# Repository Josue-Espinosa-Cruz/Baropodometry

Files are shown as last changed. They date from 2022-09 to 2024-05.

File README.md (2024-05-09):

# Baropodometry

1. **Printed Circuit Board:** 3D renders
    ~~~
    Electronic CAD: Autodesk EAGLE
    Computer-Aided Design Software: Fusion360

	1. Schematic Diagram
	2. CAD Model
	3. Renders
    ~~~
2. **Microcontroller:** Programming embedded system to acquire and visualize static plantar load distribution.
    ~~~
    Embedded System: MSP430-F5529 Launchpad
    Manufacturer:Texas Instruments 
    General specifications: 25 MHz MCU with 128KB Flash, 8KB SRAM
    ~~~

**Features applied:**
  1. GPIO pins
  2. Timer_A0
  3. 12-bit ADC
  4. UART protocol
  5. Interrupts

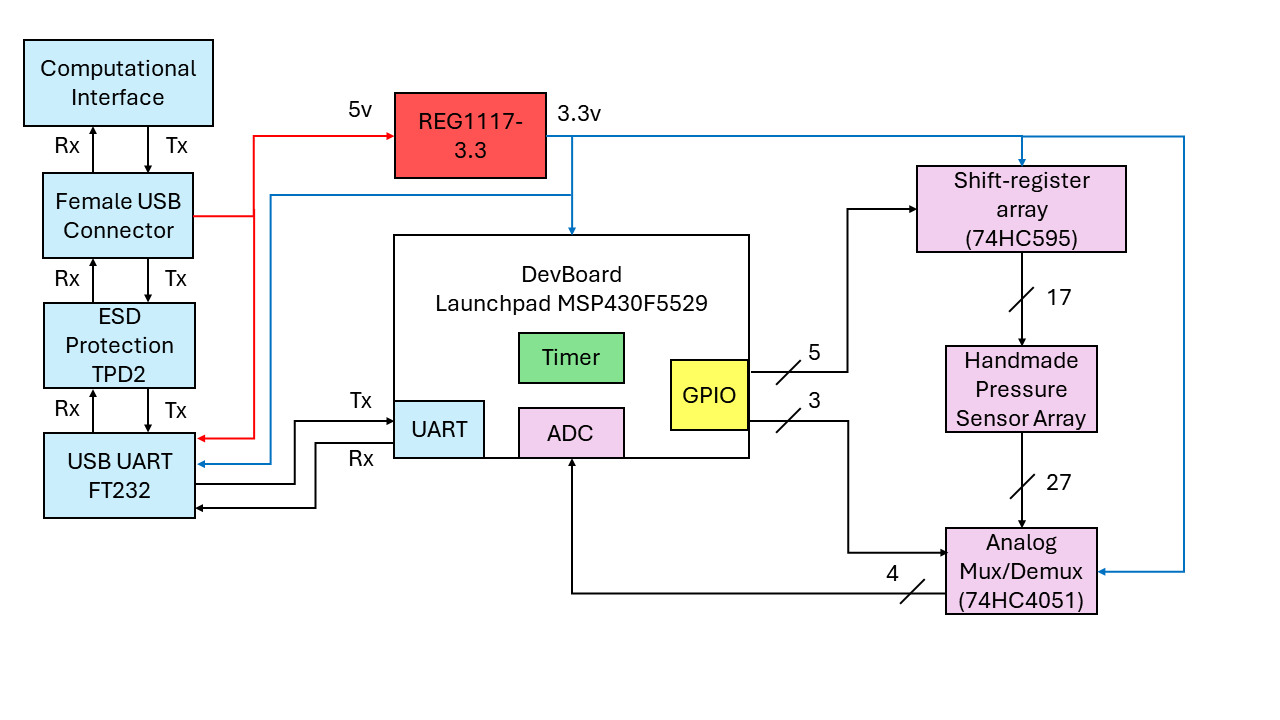
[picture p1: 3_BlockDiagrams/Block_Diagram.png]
BlockDiagram

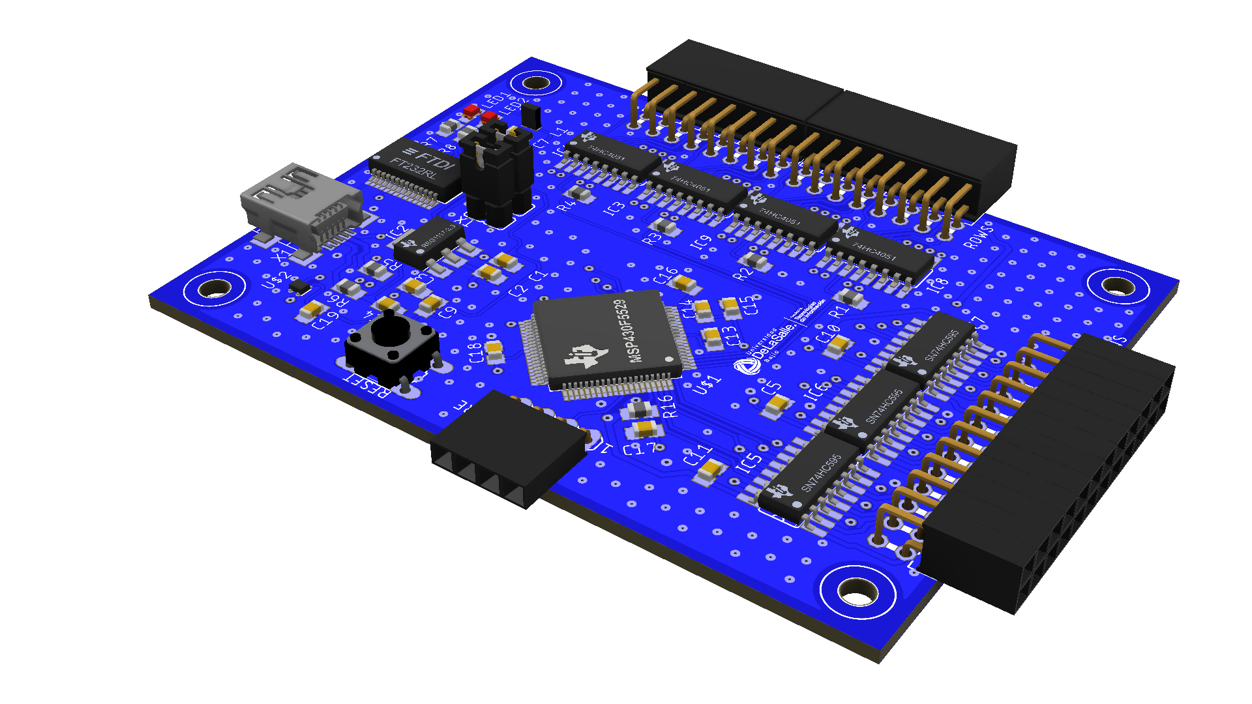
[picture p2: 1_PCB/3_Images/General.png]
PCB


## Credits
I would like to express special thanks to the following users on GrabCAD for their CAD models:

  1. Female Headers By DL2DW - Dirk Wouters
  2. Jumpler By DL2DW - Dirk Wouters
  3. Male Headers By - Vahagn Zargaryan
  4. Mini USB By [Unknown]

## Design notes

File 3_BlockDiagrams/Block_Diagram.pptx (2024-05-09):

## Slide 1

Computational Interface

5v

REG1117- 3.3

3.3v

Rx

Female USB Connector

Tx

Shift-register array
(74HC595)

DevBoard
Launchpad MSP430F5529

Rx

Tx

17

ESD Protection
TPD2

Timer

5

Handmade Pressure Sensor Array

Rx

Tx

Tx

UART

ADC

GPIO

3

USB UART
FT232

Rx

27

Analog Mux/Demux (74HC4051)

4

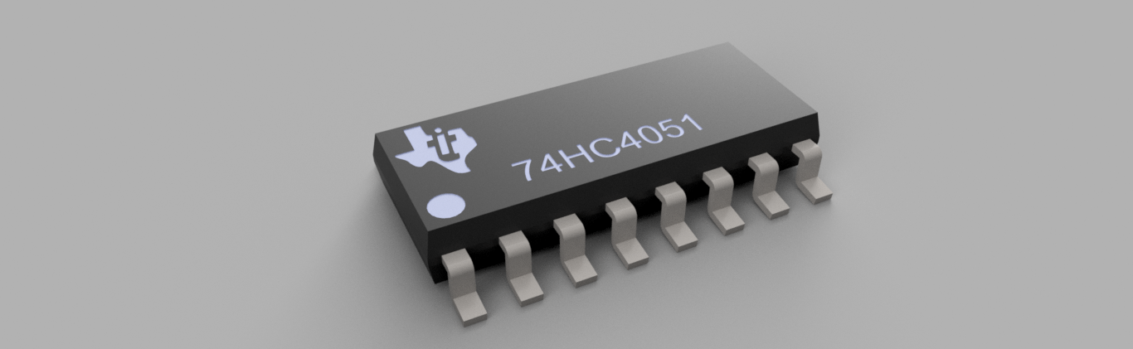
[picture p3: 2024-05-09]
1_PCB/2_CadModel/2_Components/2_OwnDesign/74HC4051-mux/74HC4051-mux_render.png

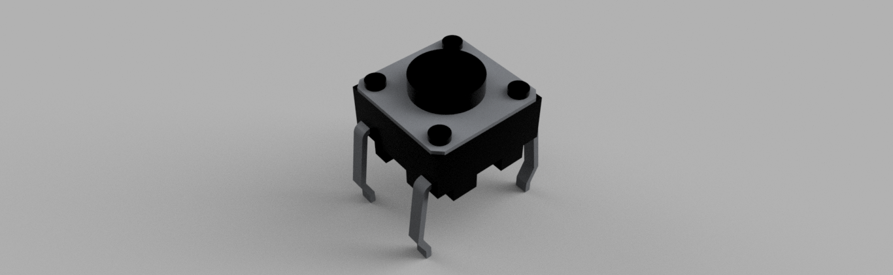
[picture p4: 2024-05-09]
1_PCB/2_CadModel/2_Components/2_OwnDesign/Pushbotton/Push.png

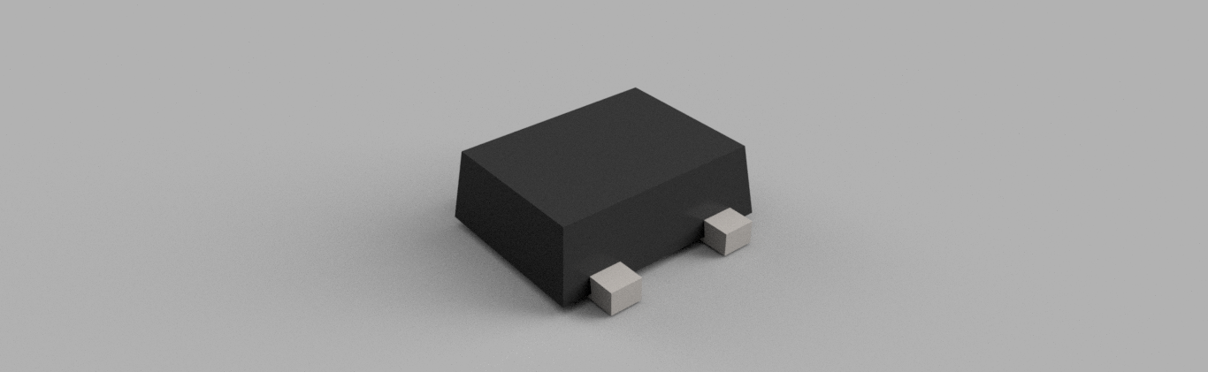
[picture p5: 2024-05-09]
1_PCB/2_CadModel/2_Components/2_OwnDesign/TP2/TPD2-render.png

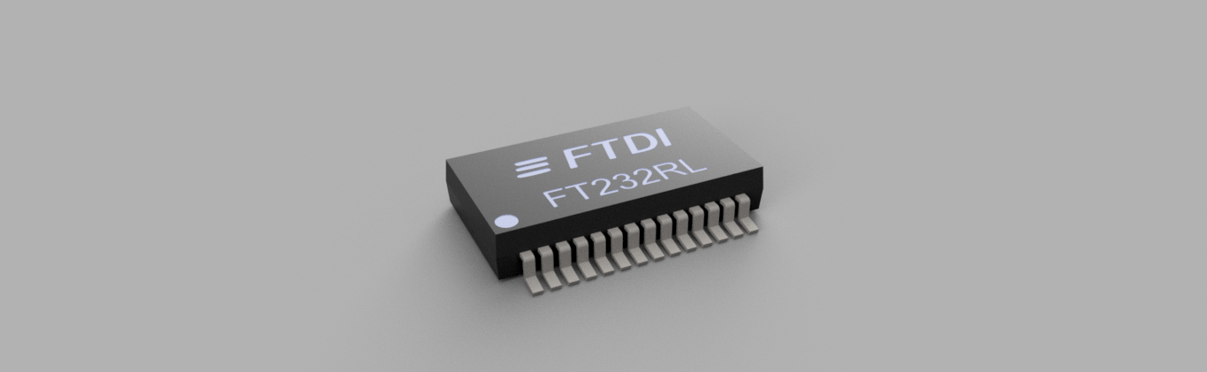
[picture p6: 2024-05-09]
1_PCB/2_CadModel/2_Components/2_OwnDesign/FT232/FT232-render.png

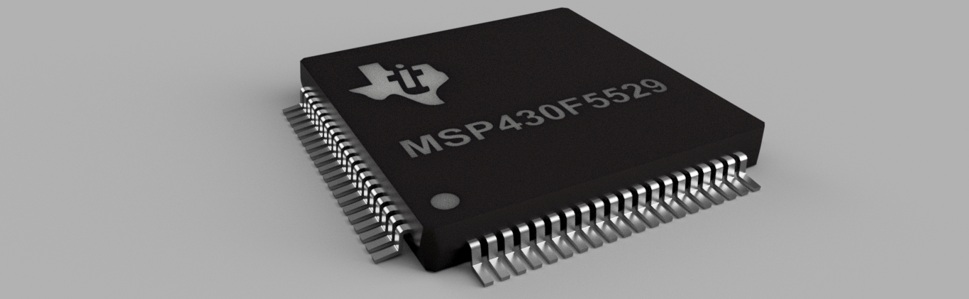
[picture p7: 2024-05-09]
1_PCB/2_CadModel/2_Components/2_OwnDesign/MSP430F5529/MSP430F5529-render.png

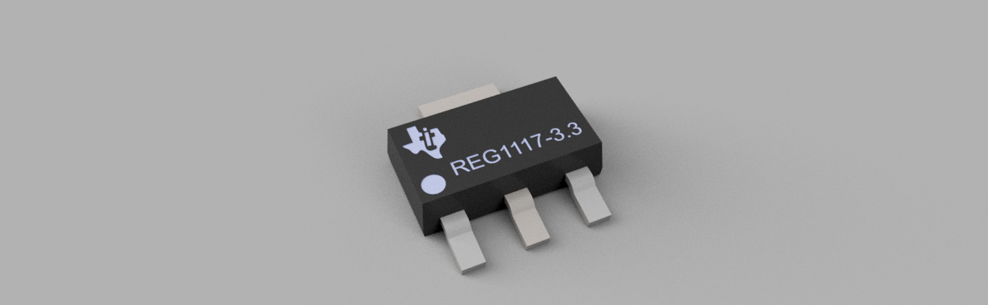
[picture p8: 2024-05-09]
1_PCB/2_CadModel/2_Components/2_OwnDesign/REG1117/REG1117-render.png

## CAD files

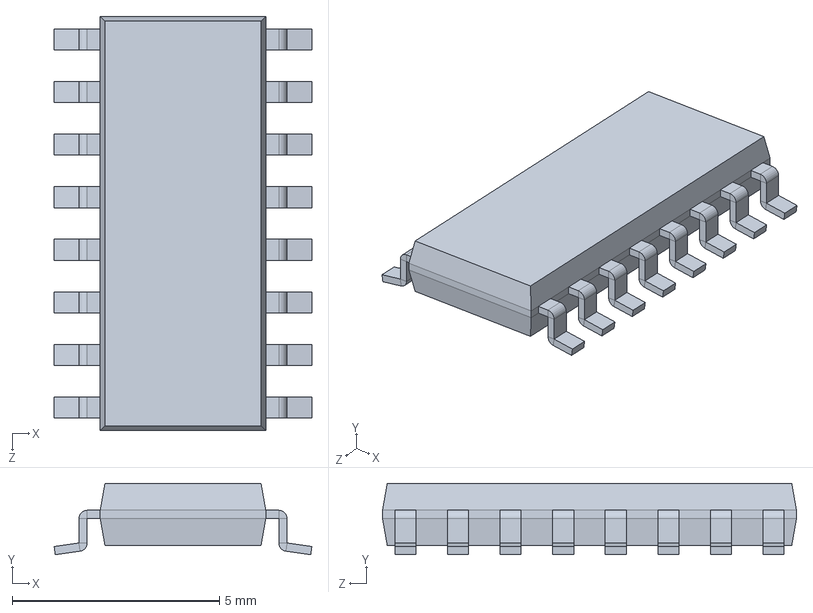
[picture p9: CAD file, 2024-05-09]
1_PCB/2_CadModel/2_Components/2_OwnDesign/74HC4051-mux/multiplexor.SLDPRT
6.23 x 1.72 x 10.0 mm

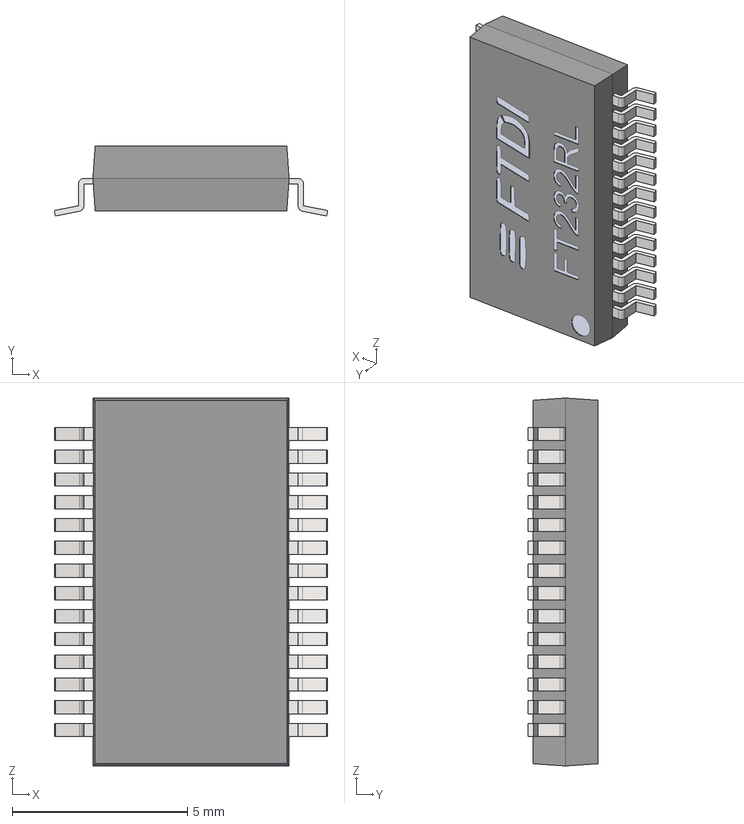
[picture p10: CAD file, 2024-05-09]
1_PCB/2_CadModel/2_Components/2_OwnDesign/FT232/FT232.STEP
7.80 x 2.00 x 10.5 mm

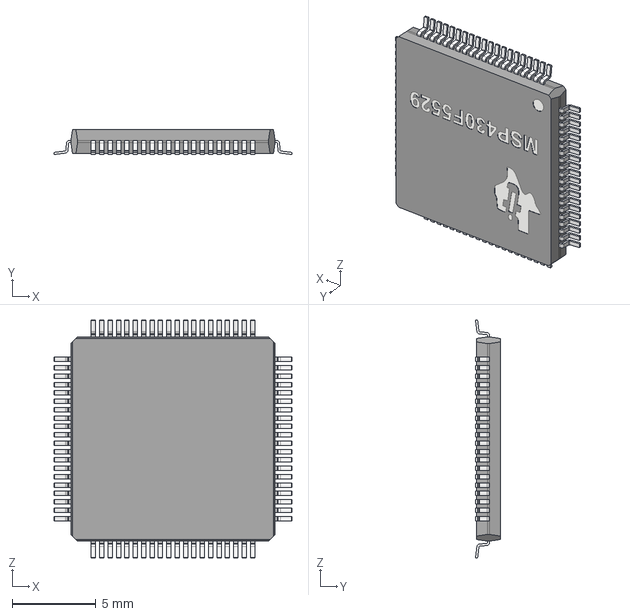
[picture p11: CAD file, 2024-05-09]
1_PCB/2_CadModel/2_Components/2_OwnDesign/MSP430F5529/MSP430F5529.step
14.2 x 1.50 x 14.2 mm

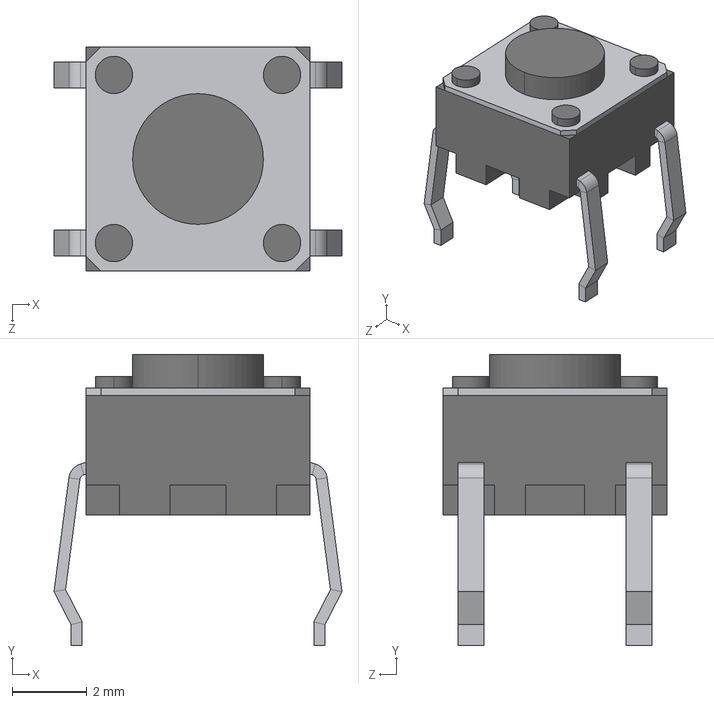
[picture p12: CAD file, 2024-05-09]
1_PCB/2_CadModel/2_Components/2_OwnDesign/Pushbotton/Push.STEP
7.71 x 7.80 x 6.00 mm

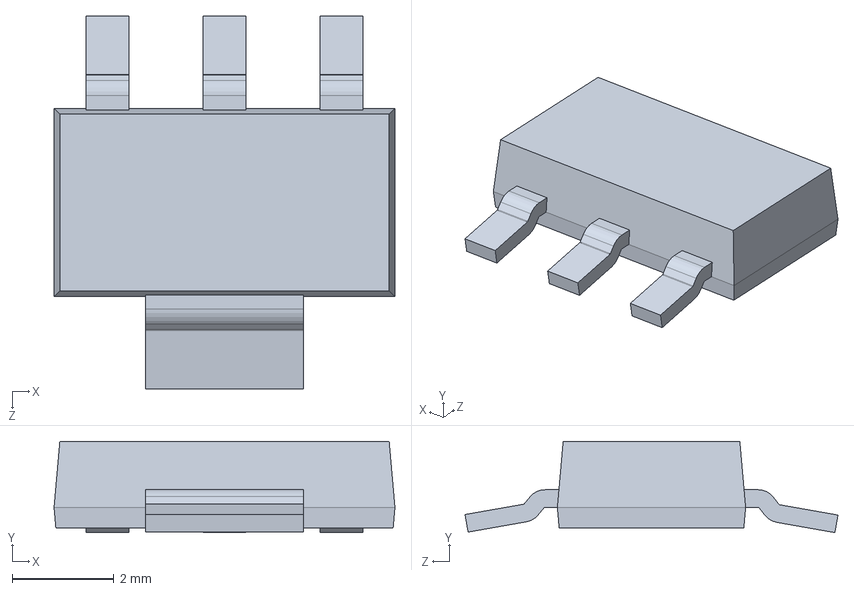
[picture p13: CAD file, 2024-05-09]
1_PCB/2_CadModel/2_Components/2_OwnDesign/REG1117/REG117.SLDPRT
6.70 x 1.79 x 7.33 mm

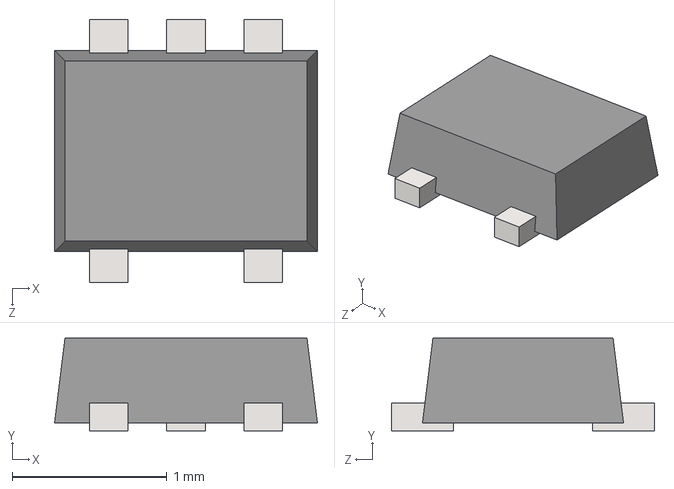
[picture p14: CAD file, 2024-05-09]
1_PCB/2_CadModel/2_Components/2_OwnDesign/TP2/TPD2.STEP
1.70 x 0.6 x 1.70 mm

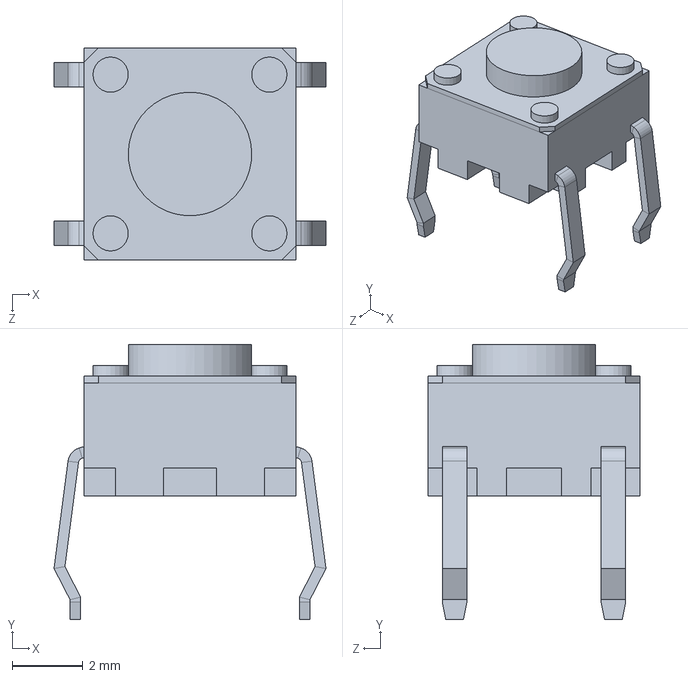
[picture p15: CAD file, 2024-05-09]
1_PCB/2_CadModel/2_Components/2_OwnDesign/Pushbotton/Push-render.SLDPRT
7.71 x 7.80 x 6.00 mm

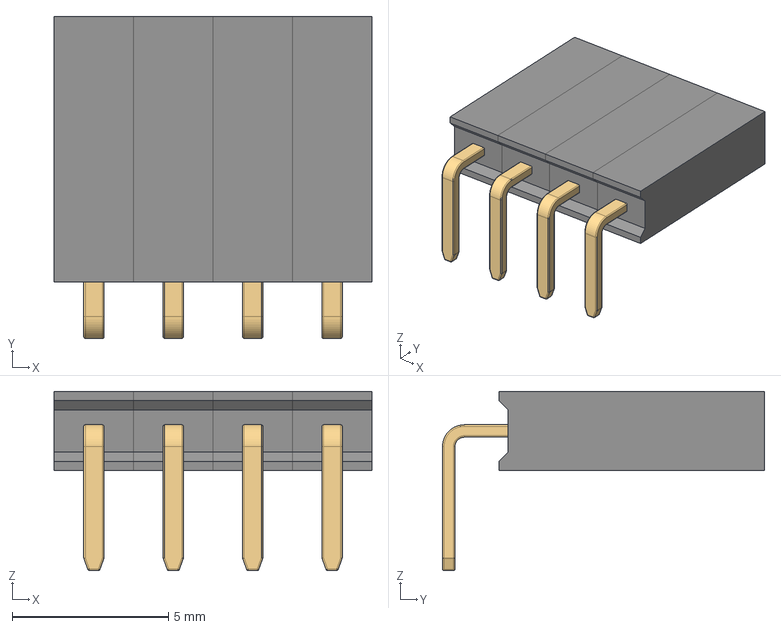
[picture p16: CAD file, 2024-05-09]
1_PCB/2_CadModel/2_Components/1_GrabCAD/Female Headers By DL2DW - Dirk Wouters/1 Row Female Pin Header Pitch 2.54mm Height 8.5mm Right Angle/Female Pin Header 01x04 Right Angle.stp
10.2 x 10.3 x 5.74 mm
Female Pin Header 1x Right Angle x 4

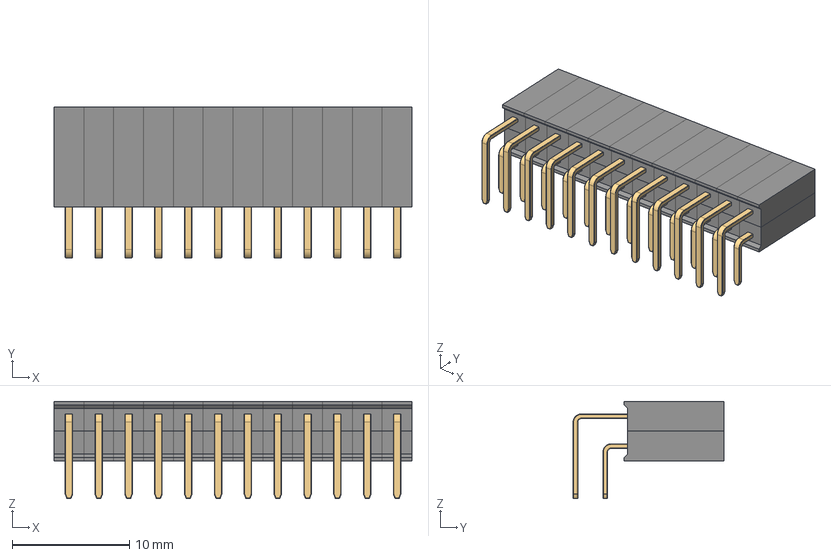
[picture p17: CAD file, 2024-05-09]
1_PCB/2_CadModel/2_Components/1_GrabCAD/Female Headers By DL2DW - Dirk Wouters/2 Row Female Pin Header Pitch 2.54mm Height 8.5mm Right Angle/Female Pin Header 02x12 Right Angle.stp
30.5 x 12.8 x 8.28 mm
Female Pin Header 1x Right Angle Upper x 12
Female Pin Header 1x Right Angle Bottom x 12

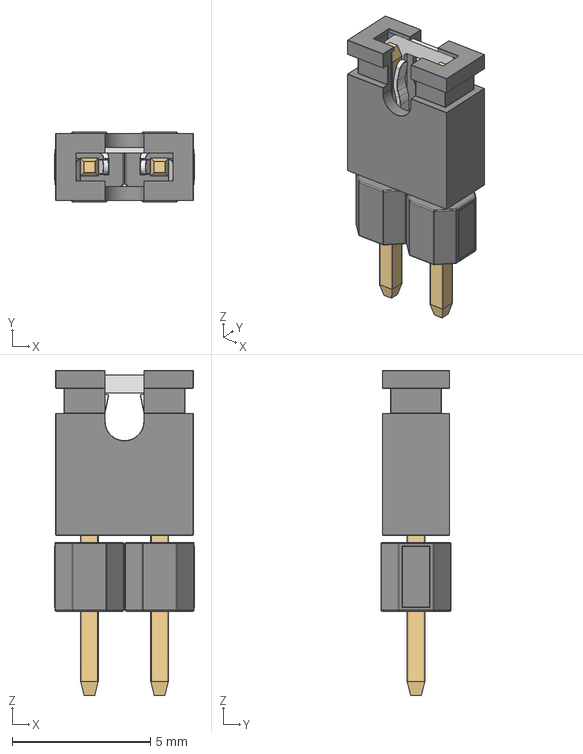
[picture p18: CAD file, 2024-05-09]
1_PCB/2_CadModel/2_Components/1_GrabCAD/Jumpler By DL2DW - Dirk Wouters/Jumper Closed.stp
5.08 x 2.54 x 11.8 mm

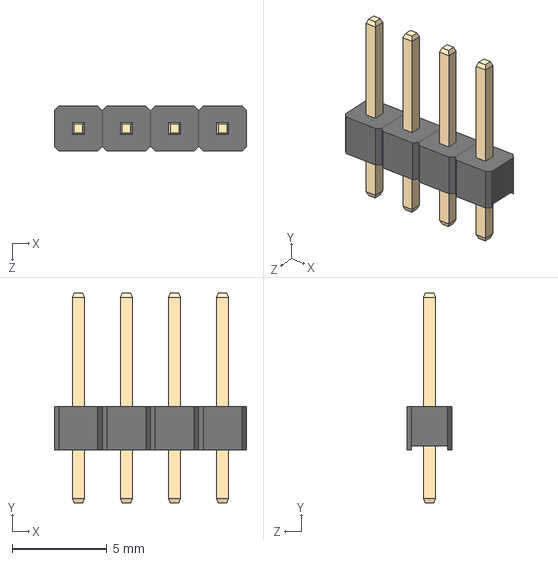
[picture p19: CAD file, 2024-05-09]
1_PCB/2_CadModel/2_Components/1_GrabCAD/Male Headers - Vahagn Zargaryan/4x_Male_Pin_2.54_mm.STEP
10.2 x 11.1 x 2.40 mm
1_Male_Pin_2.54_mm x 4

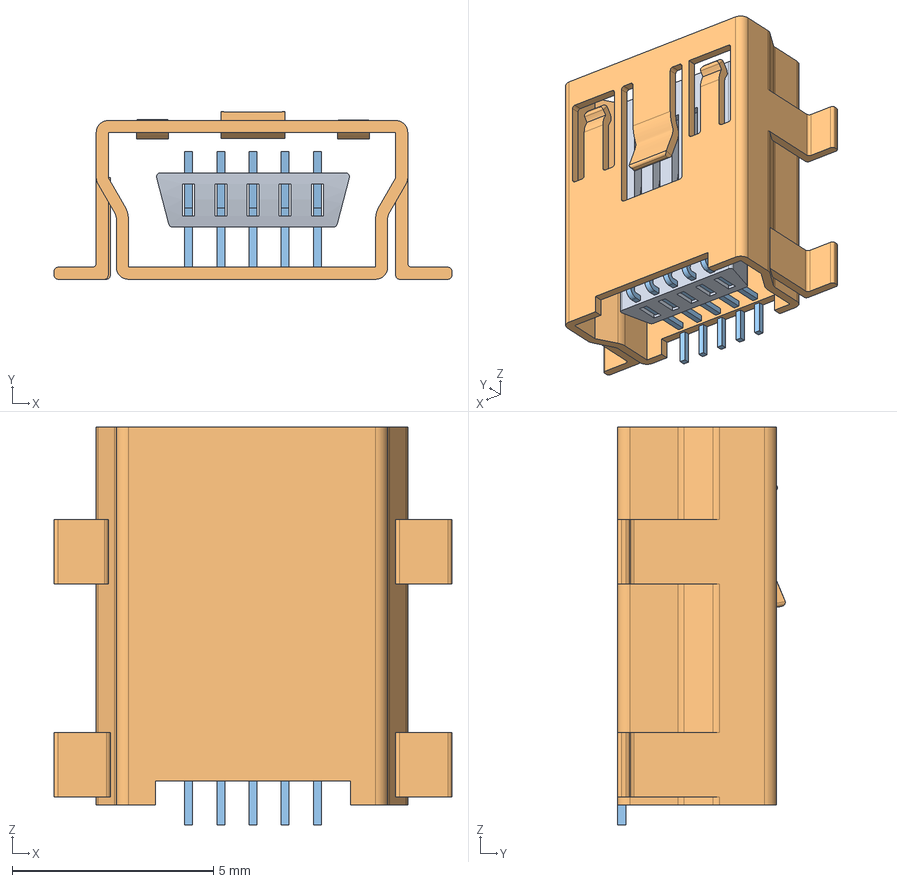
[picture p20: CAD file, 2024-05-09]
1_PCB/2_CadModel/2_Components/1_GrabCAD/Mini USB/USB_MINI_B_SMD v35.step
9.90 x 4.17 x 9.90 mm

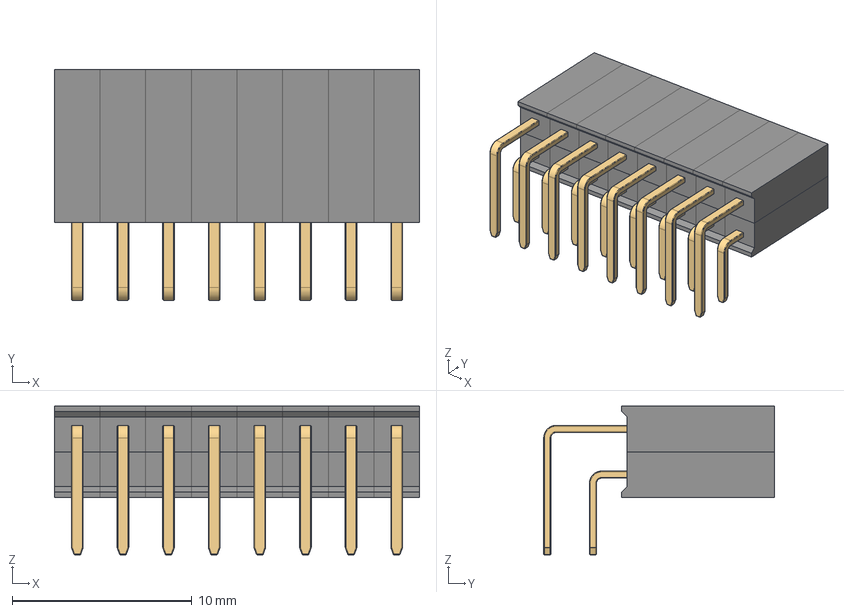
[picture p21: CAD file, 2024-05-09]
1_PCB/2_CadModel/2_Components/1_GrabCAD/Female Headers By DL2DW - Dirk Wouters/2 Row Female Pin Header Pitch 2.54mm Height 8.5mm Right Angle/Female Pin Header 02x08 Right Angle.stp
20.3 x 12.8 x 8.28 mm
Female Pin Header 1x Right Angle Upper x 8
Female Pin Header 1x Right Angle Bottom x 8

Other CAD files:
1_PCB/2_CadModel/2_Components/2_OwnDesign/74HC595-shift/74HC595-shift.step
1_PCB/2_CadModel/2_Components/2_OwnDesign/74HC4051-mux/74HC4051-mux.step
1_PCB/2_CadModel/2_Components/2_OwnDesign/REG1117/REG1117.step
1_PCB/2_CadModel/2_Components/1_GrabCAD/Mini USB/USB_MINI_B_SMD v35.f3d
1_PCB/2_CadModel/2_Components/2_OwnDesign/74HC4051-mux/74HC4051-mux.f3d
1_PCB/2_CadModel/2_Components/2_OwnDesign/74HC595-shift/74HC595-shift.f3d
1_PCB/2_CadModel/2_Components/2_OwnDesign/FT232/FT232.SLDPRT
1_PCB/2_CadModel/2_Components/2_OwnDesign/FT232/FT232.f3d
1_PCB/2_CadModel/2_Components/2_OwnDesign/MSP430F5529/MSP430F5529.f3d
1_PCB/2_CadModel/2_Components/2_OwnDesign/REG1117/REG1117.f3d
1_PCB/2_CadModel/2_Components/2_OwnDesign/TP2/TPD2.SLDPRT

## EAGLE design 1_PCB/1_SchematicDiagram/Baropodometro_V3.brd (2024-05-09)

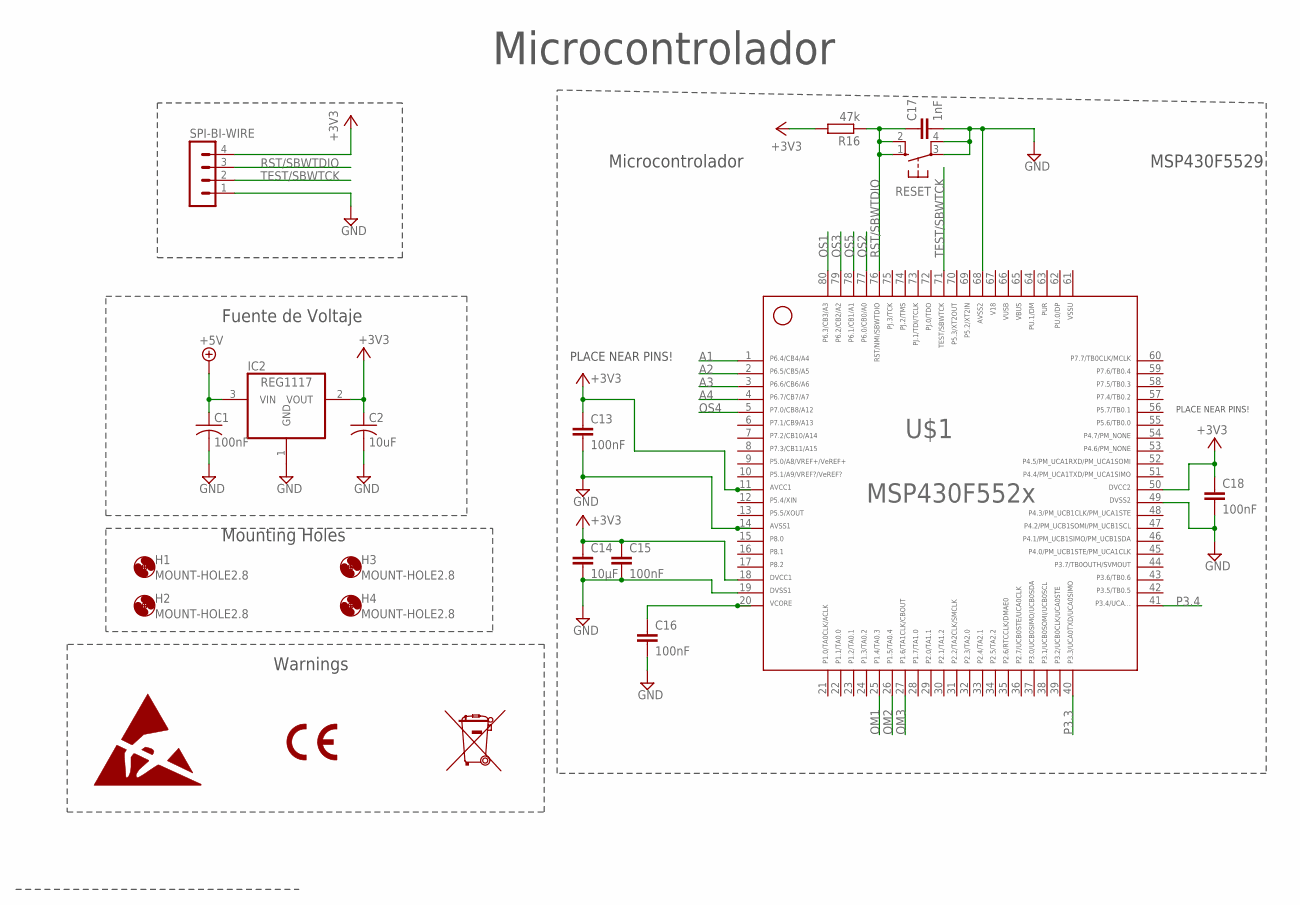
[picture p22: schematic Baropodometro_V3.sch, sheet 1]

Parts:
C1, C13, C15, C16, C18: 100nF; C0805
C2: 10uF; C0805
C14: 10µF; C0805
C17: 1nF; C0805
H1, H2, H3, H4: MOUNT-HOLE2.8; 2,8
IC2: REG1117; SOT223
R16: 47k; R0805
RESET: 10-XX; B3F-10XX
SPI-BI-WIRE: MA04-1
U$1: MSP430F5529; TI_MSP430_V16_INTERN_PN80

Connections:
61: U$1.61
65: U$1.65
66: U$1.66
67: U$1.67
+3V3: C2.1, C13.1, C14.1, C15.1, C18.1, IC2.2 (VOUT), R16.2, SPI-BI-WIRE.4, U$1.11, U$1.18, U$1.50; also elsewhere on the board
+5V: C1.1, IC2.3 (VIN); also elsewhere on the board
A1: U$1.1; also elsewhere on the board
A2: U$1.2; also elsewhere on the board
A3: U$1.3; also elsewhere on the board
A4: U$1.4; also elsewhere on the board
GND: C1.2, C2.2, C13.2, C14.2, C15.2, C16.2, C17.2, C18.2, IC2.1 (GND), RESET.3, RESET.4 (P1), SPI-BI-WIRE.1, U$1.14, U$1.19, U$1.49, U$1.68; also elsewhere on the board
unnamed: C16.1, U$1.20
OM1: U$1.25; also elsewhere on the board
OM2: U$1.26; also elsewhere on the board
OM3: U$1.27; also elsewhere on the board
OS1: U$1.80; also elsewhere on the board
OS2: U$1.77; also elsewhere on the board
OS3: U$1.79; also elsewhere on the board
OS4: U$1.5; also elsewhere on the board
OS5: U$1.78; also elsewhere on the board
P3.3: U$1.40; also elsewhere on the board
P3.4: U$1.41; also elsewhere on the board
RST/SBWTDIO: C17.1, R16.1, RESET.1 (S), RESET.2 (S1), SPI-BI-WIRE.3, U$1.76
TEST/SBWTCK: SPI-BI-WIRE.2, U$1.71

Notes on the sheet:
Fuente de Voltaje
Microcontrolador
MSP430F5529
Warnings
Mounting Holes
PLACE NEAR PINS!

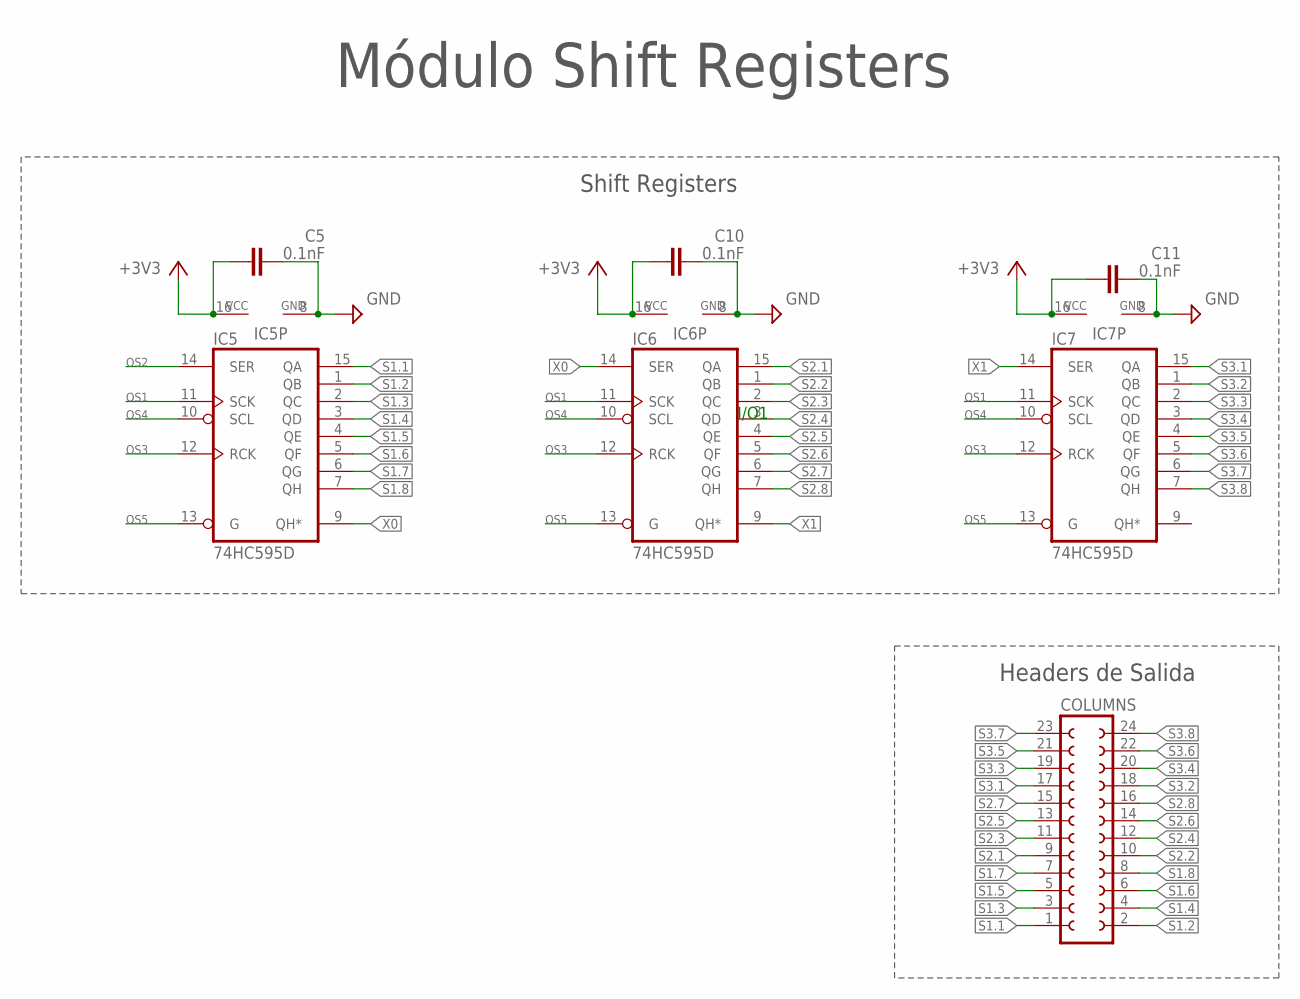
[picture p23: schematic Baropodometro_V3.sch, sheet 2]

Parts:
C5, C10, C11: 0.1nF; C0805
COLUMNS: FE12-2W
IC5, IC6, IC7: 74HC595D; SO16

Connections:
+3V3: C5.1, C10.1, C11.1, IC5.16 (VCC), IC6.16 (VCC), IC7.16 (VCC); also elsewhere on the board
GND: C5.2, C10.2, C11.2, IC5.8 (GND), IC6.8 (GND), IC7.8 (GND); also elsewhere on the board
OS1: IC5.11 (SCK), IC6.11 (SCK), IC7.11 (SCK); also elsewhere on the board
OS2: IC5.14 (SER); also elsewhere on the board
OS3: IC5.12 (RCK), IC6.12 (RCK), IC7.12 (RCK); also elsewhere on the board
OS4: IC5.10 (SCL), IC6.10 (SCL), IC7.10 (SCL); also elsewhere on the board
OS5: IC5.13 (G), IC6.13 (G), IC7.13 (G); also elsewhere on the board
S1.1: COLUMNS.1, IC5.15 (QA)
S1.2: COLUMNS.2, IC5.1 (QB)
S1.3: COLUMNS.3, IC5.2 (QC)
S1.4: COLUMNS.4, IC5.3 (QD)
S1.5: COLUMNS.5, IC5.4 (QE)
S1.6: COLUMNS.6, IC5.5 (QF)
S1.7: COLUMNS.7, IC5.6 (QG)
S1.8: COLUMNS.8, IC5.7 (QH)
S2.1: COLUMNS.9, IC6.15 (QA)
S2.2: COLUMNS.10, IC6.1 (QB)
S2.3: COLUMNS.11, IC6.2 (QC)
S2.4: COLUMNS.12, IC6.3 (QD)
S2.5: COLUMNS.13, IC6.4 (QE)
S2.6: COLUMNS.14, IC6.5 (QF)
S2.7: COLUMNS.15, IC6.6 (QG)
S2.8: COLUMNS.16, IC6.7 (QH)
S3.1: COLUMNS.17, IC7.15 (QA)
S3.2: COLUMNS.18, IC7.1 (QB)
S3.3: COLUMNS.19, IC7.2 (QC)
S3.4: COLUMNS.20, IC7.3 (QD)
S3.5: COLUMNS.21, IC7.4 (QE)
S3.6: COLUMNS.22, IC7.5 (QF)
S3.7: COLUMNS.23, IC7.6 (QG)
S3.8: COLUMNS.24, IC7.7 (QH)
X0: IC5.9 (QH*), IC6.14 (SER)
X1: IC6.9 (QH*), IC7.14 (SER)

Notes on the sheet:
I/O1
Shift Registers
Módulo Shift Registers
Headers de Salida

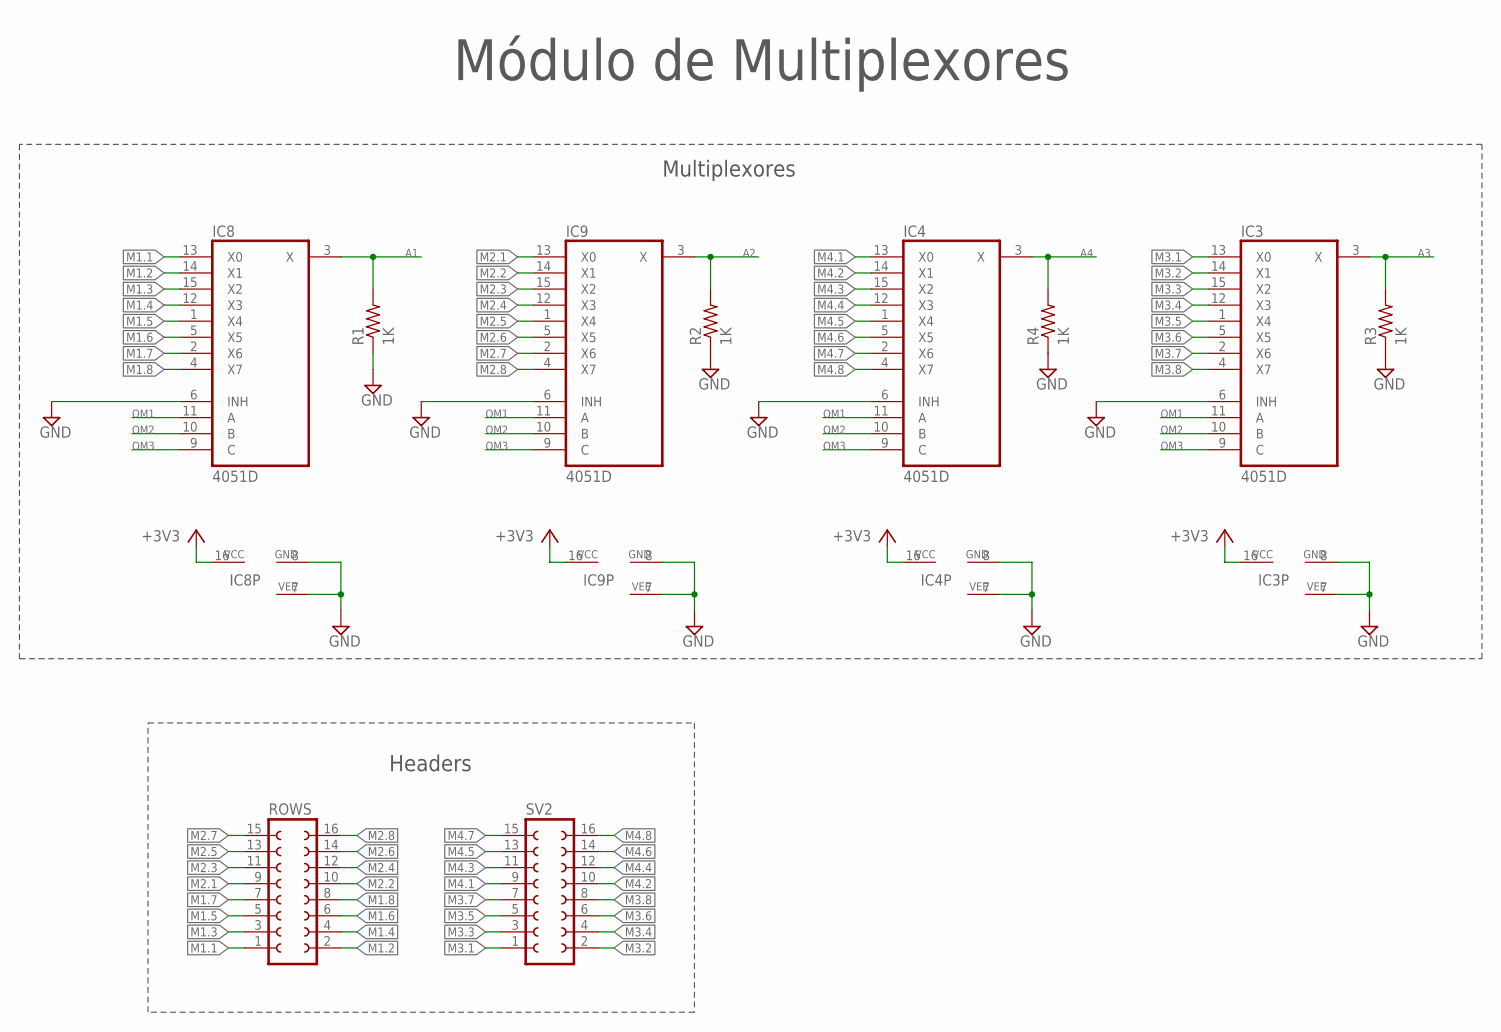
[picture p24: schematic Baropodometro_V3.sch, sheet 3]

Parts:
IC3, IC4, IC8, IC9: 4051D; SO16
R1, R2, R3, R4: 1K; R0805
ROWS: FE08-2W
SV2: FE08-2W

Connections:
+3V3: IC3.16 (VCC), IC4.16 (VCC), IC8.16 (VCC), IC9.16 (VCC); also elsewhere on the board
A1: IC8.3 (X), R1.2; also elsewhere on the board
A2: IC9.3 (X), R2.2; also elsewhere on the board
A3: IC3.3 (X), R3.2; also elsewhere on the board
A4: IC4.3 (X), R4.2; also elsewhere on the board
GND: IC3.6 (INH), IC3.7 (VEE), IC3.8 (GND), IC4.6 (INH), IC4.7 (VEE), IC4.8 (GND), IC8.6 (INH), IC8.7 (VEE), IC8.8 (GND), IC9.6 (INH), IC9.7 (VEE), IC9.8 (GND), R1.1, R2.1, R3.1, R4.1; also elsewhere on the board
M1.1: IC8.13 (X0), ROWS.1
M1.2: IC8.14 (X1), ROWS.2
M1.3: IC8.15 (X2), ROWS.3
M1.4: IC8.12 (X3), ROWS.4
M1.5: IC8.1 (X4), ROWS.5
M1.6: IC8.5 (X5), ROWS.6
M1.7: IC8.2 (X6), ROWS.7
M1.8: IC8.4 (X7), ROWS.8
M2.1: IC9.13 (X0), ROWS.9
M2.2: IC9.14 (X1), ROWS.10
M2.3: IC9.15 (X2), ROWS.11
M2.4: IC9.12 (X3), ROWS.12
M2.5: IC9.1 (X4), ROWS.13
M2.6: IC9.5 (X5), ROWS.14
M2.7: IC9.2 (X6), ROWS.15
M2.8: IC9.4 (X7), ROWS.16
M3.1: IC3.13 (X0), SV2.1
M3.2: IC3.14 (X1), SV2.2
M3.3: IC3.15 (X2), SV2.3
M3.4: IC3.12 (X3), SV2.4
M3.5: IC3.1 (X4), SV2.5
M3.6: IC3.5 (X5), SV2.6
M3.7: IC3.2 (X6), SV2.7
M3.8: IC3.4 (X7), SV2.8
M4.1: IC4.13 (X0), SV2.9
M4.2: IC4.14 (X1), SV2.10
M4.3: IC4.15 (X2), SV2.11
M4.4: IC4.12 (X3), SV2.12
M4.5: IC4.1 (X4), SV2.13
M4.6: IC4.5 (X5), SV2.14
M4.7: IC4.2 (X6), SV2.15
M4.8: IC4.4 (X7), SV2.16
OM1: IC3.11 (A), IC4.11 (A), IC8.11 (A), IC9.11 (A); also elsewhere on the board
OM2: IC3.10 (B), IC4.10 (B), IC8.10 (B), IC9.10 (B); also elsewhere on the board
OM3: IC3.9 (C), IC4.9 (C), IC8.9 (C), IC9.9 (C); also elsewhere on the board

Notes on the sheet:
Headers
Multiplexores
Módulo de Multiplexores

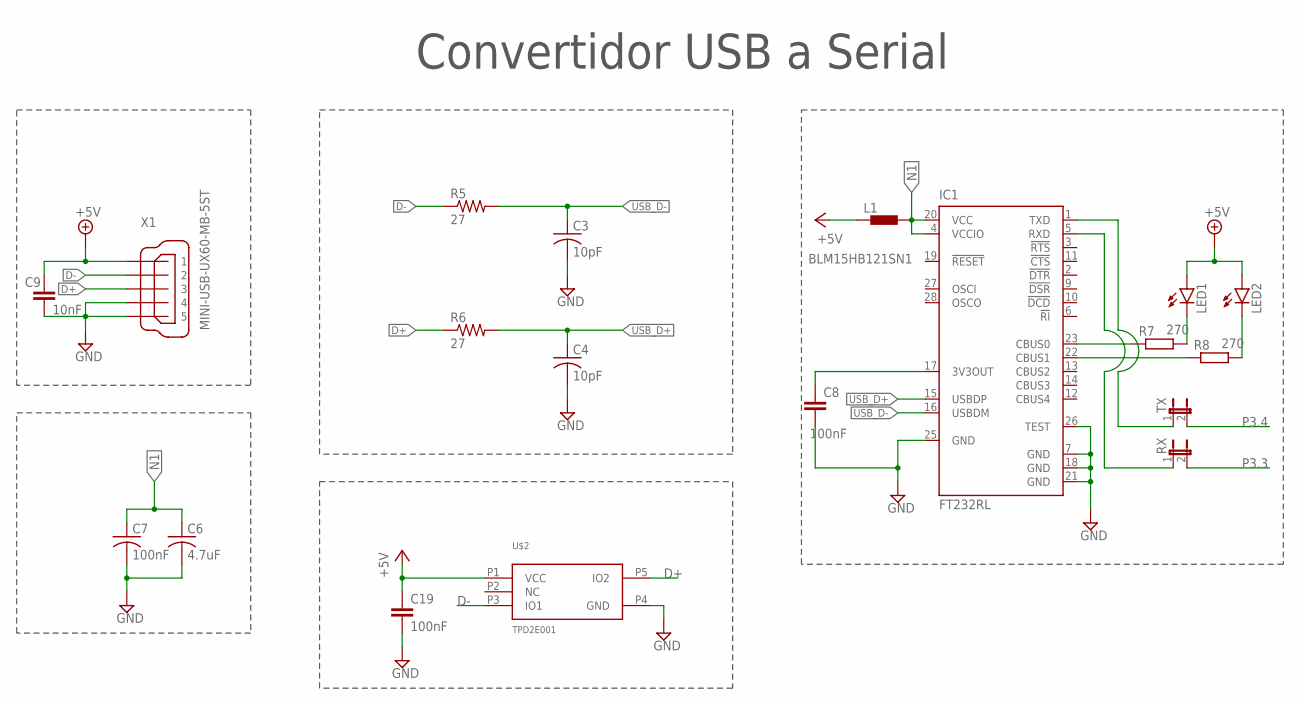
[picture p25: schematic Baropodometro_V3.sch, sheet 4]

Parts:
C3, C4: 10pF; C0805
C6: 4.7uF; C0805
C7, C8, C19: 100nF; C0805
C9: 10nF; C0805
IC1: FT232RL; SSOP28
L1: BLM15HB121SN1; 0402
LED1, LED2: LEDCHIP-LED0805; CHIP-LED0805
R5, R6: 27; R0805
R7, R8: 270; R0805
RX: JP1E; JP1
TX: JP1E; JP1
U$2: TPD2E001; SOT-5
X1: MINI-USB-UX60-MB-5ST; UX60-MB-5ST

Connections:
+5V: C9.1, C19.1, L1.1, LED1.A, LED2.A, U$2.P1 (VCC), X1.1; also elsewhere on the board
D+: R6.1, U$2.P5 (IO2), X1.3
D-: R5.1, U$2.P3 (IO1), X1.2
GND: C3.2, C4.2, C6.2, C7.2, C8.2, C9.2, C19.2, IC1.7 (GND), IC1.18 (GND), IC1.21 (GND), IC1.25 (GND), IC1.26 (TEST), U$2.P4 (GND), X1.4, X1.5; also elsewhere on the board
N1: C6.1, C7.1, IC1.4 (VCCIO), IC1.20 (VCC), L1.2
unnamed: LED1.C, R7.2
unnamed: IC1.22 (CBUS1), R8.1
unnamed: IC1.23 (CBUS0), R7.1
unnamed: LED2.C, R8.2
unnamed: IC1.1 (TXD), TX.1
unnamed: IC1.5 (RXD), RX.1
unnamed: C8.1, IC1.17 (3V3OUT)
P3.3: RX.2; also elsewhere on the board
P3.4: TX.2; also elsewhere on the board
USB_D+: C4.1, IC1.15 (USBDP), R6.2
USB_D-: C3.1, IC1.16 (USBDM), R5.2

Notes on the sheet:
Convertidor USB a Serial

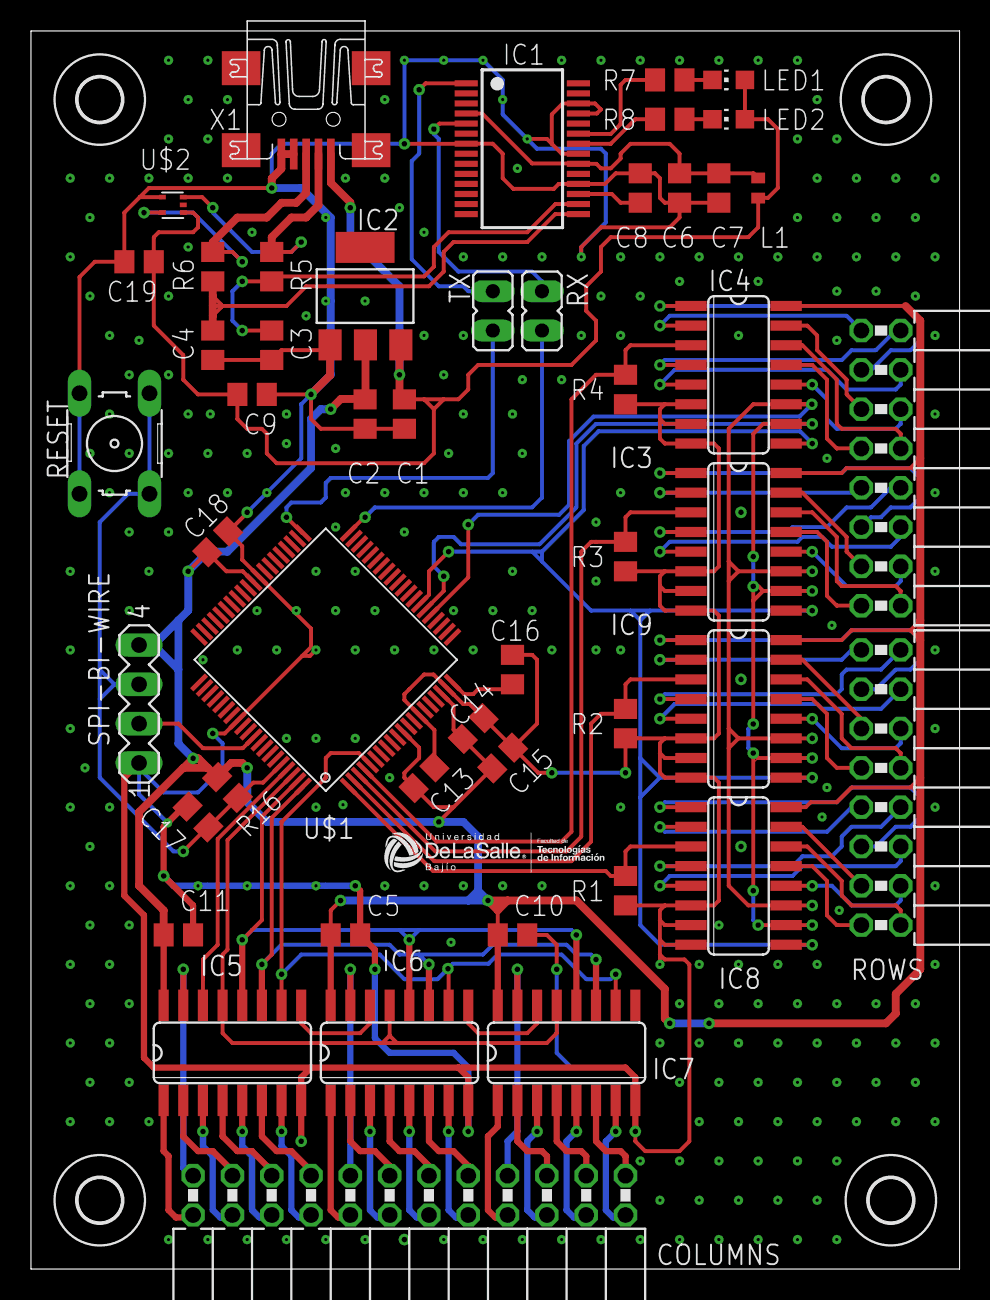
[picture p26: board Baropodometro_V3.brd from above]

Board: 2 copper layers, 60.0 x 80.0 mm, 53 parts (0 on the bottom side), 90 nets.

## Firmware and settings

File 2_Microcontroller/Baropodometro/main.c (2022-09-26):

#include <msp430.h>

/**
 * main.c
 *  Autor: C. Josué Espinosa Cruz
 *  Fecha: 10 de mayo de 2020
 *
 *
 *  El voltaje se varía con un potenciómetro externo.
 */

unsigned int valor_adc_binario1 = 0;
unsigned int valor_adc_binario2 = 0;
unsigned int valor_adc_binario3 = 0;
unsigned int valor_adc_binario4 = 0;

unsigned int tx_buffer[459]; //unsigned char

unsigned char i = 0;

unsigned char bandera_inicializar = 0x00;
unsigned int contador_general = 0;
unsigned int contador_timer = 0;
unsigned int contador_timer2 = 0;
unsigned int contador_timer3 = 0;

unsigned int contador_arreglo1 = 0;
unsigned int contador_arreglo2 = 8;
unsigned int contador_arreglo3 = 16;
unsigned int contador_arreglo4 = 24;

unsigned int contador_arreglo1_2 = 0;
unsigned int contador_arreglo2_2 = 0;
unsigned int contador_arreglo3_2 = 0;
unsigned int contador_arreglo4_2 = 0;

unsigned char banderaADC_Activar = 0x00;
unsigned char banderaTimer_Activar = 0x00;

void Configurar_GPIO(void)
{
    //Señal_Funcionamiento_TimerA0
    P1DIR |= 0x01;                                   // Se configura el bit 0 del puerto 1 como salida. Los demás bits, como entrada.
    P1OUT = 0x00;                                   // Se ponen todos los pines del puerto 1 en 0 (en LOW).

    //Output Contador_Multiplexor_Columnas
    P4DIR |= 0x09;                                  // Se configura el bit 0 y 3 del puerto 4 como salida. Los demás bits, como entrada.
    P3DIR |= BIT7;                                  // Se configura el bit 7 del puerto 3 como salida. Los demás bits, como entrada.

    P4OUT &= ~0x09;
    P3OUT &= ~BIT7;

    //Output Control_Shift_Registers
    P1DIR |= 0x3C;                                  // Se configura el bit 2, 3, 4 y 5 del puerto 1 como salida. Los demás bits, como entrada.
    P1OUT &= ~0x3C;                                 // Se mandan a 0 todos los bits
    P1OUT |= 0x1C;                                  // Se mandan a positivos para que inicie "0111"
}

void Configurar_TimerA(void)
{
    TA0CCTL0 = CCIE;                                // Activa la interrupción por CCR.
    TA0CCR0 = 130;                                // Configura el Capture Compare Register a aprox. (1/131072)*131 = 1ms

                                                    //Carga cuenta en TA1CCR0 0.1seg TA1CCR=(0.1*32768)-1
    TA0CTL |= TASSEL_2 | MC_1 | ID_3 | TACLR;       // SMCK= 1048576Hz | UP mode | Divisor de DCO / 8 | limpieza de registro TAR (contador del Timer)
}                                                   //1048576Hz/8 = 131072 Hz

void Configurar_ADC(void)
{
    P6SEL |= 0xF;            // Se selecciona el bit 0, 1, 2 y 3 del puerto 6 como Analog Input.
    ADC12CTL0 |= ADC12SHT0_2 | ADC12ON;     // Se enciende el ADC
    ADC12CTL1 = ADC12SHP;                   // Se selecciona el Sampling Timer como reloj de conversión
    ADC12MCTL0 |= ADC12INCH_0;                      // Se selecciona el canal A0 (P6.0)
    ADC12MCTL1 |= ADC12INCH_1;                      // Se selecciona el canal A1 (P6.1)
    ADC12MCTL2 |= ADC12INCH_2;                      // Se selecciona el canal A2 (P6.2)
    ADC12MCTL3 |= ADC12INCH_3;                      // Se selecciona el canal A3 (P6.3)
}

void Configurar_UART(void)
{
    P4SEL |= 0x30;                   // P4.4 TXD P4.5 RXD
    UCA1CTL1 |= UCSWRST;            // Configurar State Machine en modo Reset para modificar los demás registros
    UCA1CTL1 |= UCSSEL_2;           // Seleccionar SMCLK como reloj
    UCA1BR0 = 109;                  // 9600 bauds @ ~1MHz (User's guide, página 952)
    UCA1BR1 = 0;                    // 1MHz 9600
    UCA1MCTL = UCBRS_1;             // 9600 bauds @ ~1MHz (User's guide, página 952)

    UCA1CTL1 &= ~UCSWRST;           // Inicializa la State Machine del USCI
    UCA1IE |= UCRXIE;               // Activa las interrupciones de RX
}

void Adquirir_ADC_Canal0(void)
{
    ADC12CTL1 |= ADC12CSTARTADD_0;                  //Se selecciona la ubicación MEM a guardar la información (MEM0)

    ADC12CTL0 |= ADC12ENC;                          // Se activan las conversiones
    ADC12CTL0 |= ADC12SC;                           // Inicia la conversión

    while (!(ADC12IFG & 0x01));                    // Espera mientras esté ocupado el ADC.
    valor_adc_binario1 = ADC12MEM0;                 // Lee el valor del registro ADC12MEM0

    ADC12CTL0 &= ~ADC12ENC;                          // Se desactivan las conversiones
    ADC12CTL1 &= ~ADC12CSTARTADD_0;                  //Se selecciona la ubicación MEM a guardar la información (MEM0)
}

void Adquirir_ADC_Canal1(void)
{
    ADC12CTL1 |= ADC12CSTARTADD_1;                  //Se selecciona la ubicación MEM a guardar la información (MEM1)

    ADC12CTL0 |= ADC12ENC;                          // Se activan las conversiones
    ADC12CTL0 |= ADC12SC;                           // Inicia la conversión

    while (!(ADC12IFG & 0x02));                    // Espera mientras esté ocupado el ADC.
    valor_adc_binario2 = ADC12MEM1;                 // Lee el valor del registro ADC12MEM0

    ADC12CTL0 &= ~ADC12ENC;                          // Se desactivan las conversiones
    ADC12CTL1 &= ~ADC12CSTARTADD_1;                  //Se selecciona la ubicación MEM a guardar la información (MEM1)
}

void Adquirir_ADC_Canal2(void)
{
    ADC12CTL1 |= ADC12CSTARTADD_2;                  //Se selecciona la ubicación MEM a guardar la información (MEM2)

    ADC12CTL0 |= ADC12ENC;                          // Se activan las conversiones
    ADC12CTL0 |= ADC12SC;                           // Inicia la conversión

    while (!(ADC12IFG & 0x04));                    // Espera mientras esté ocupado el ADC.
    valor_adc_binario3 = ADC12MEM2;                 // Lee el valor del registro ADC12MEM0

    ADC12CTL0 &= ~ADC12ENC;                          // Se desactivan las conversiones
    ADC12CTL1 &= ~ADC12CSTARTADD_2;                  //Se selecciona la ubicación MEM a guardar la información (MEM2)
}

void Adquirir_ADC_Canal3(void)
{
    ADC12CTL1 |= ADC12CSTARTADD_3;                  //Se selecciona la ubicación MEM a guardar la información (MEM2)

    ADC12CTL0 |= ADC12ENC;                          // Se activan las conversiones
    ADC12CTL0 |= ADC12SC;                           // Inicia la conversión

    while (!(ADC12IFG & 0x08));                    // Espera mientras esté ocupado el ADC.
    valor_adc_binario4 = ADC12MEM3;                 // Lee el valor del registro ADC12MEM0

    ADC12CTL0 &= ~ADC12ENC;                          // Se desactivan las conversiones
    ADC12CTL1 &= ~ADC12CSTARTADD_3;                  //Se selecciona la ubicación MEM a guardar la información (MEM2)
}

void Transformar_Informacion_ADC1(void)
{

    if(contador_arreglo1_2<=7)
    {
        tx_buffer[contador_arreglo1] = valor_adc_binario1 / 16;
        contador_arreglo1++;
        contador_arreglo1_2++;
    }
    else if(contador_arreglo1_2==8)
    {
        contador_arreglo1=contador_arreglo1 + 20;
        contador_arreglo1_2 = 0;
    }
}

void Transformar_Informacion_ADC2(void)
{
    if(contador_arreglo2_2<=7)
    {
        tx_buffer[contador_arreglo2] = valor_adc_binario2 / 16;
        contador_arreglo2++;
        contador_arreglo2_2++;
    }
    else if(contador_arreglo2_2==8)
    {
        contador_arreglo2=contador_arreglo2 + 20;
        contador_arreglo2_2 = 0;
    }
}

void Transformar_Informacion_ADC3(void)
{
    if(contador_arreglo3_2<=7)
    {
        tx_buffer[contador_arreglo3] = valor_adc_binario3/16;
        contador_arreglo3++;
        contador_arreglo3_2++;
    }
    else if(contador_arreglo3_2==8)
    {
        contador_arreglo3=contador_arreglo3 + 20;
        contador_arreglo3_2 = 0;
    }

}

void Transformar_Informacion_ADC4(void)
{
    if(contador_arreglo4_2<=2)
    {
        tx_buffer[contador_arreglo4] = valor_adc_binario4 / 16;
    }
    else if(contador_arreglo4_2==7)
    {
        contador_arreglo4=contador_arreglo4 + 20;
        contador_arreglo4_2 = 0;
    }

    contador_arreglo4++;
    contador_arreglo4_2++;
}

void Mandar_Informacion(void)
{
    for(i = 0; i < 255; i++)                           //sizeof(tx_buffer)
    {
        while (!(UCA1IFG & UCTXIFG));               // Espera mientras envía un byte, es decir, si hay pendiente algo por enviar
        UCA1TXBUF = tx_buffer[i];                   // Envía un byte a la vez
    }
    for(i = 1; i < 204; i++)                           //sizeof(tx_buffer)
    {
        while (!(UCA1IFG & UCTXIFG));               // Espera mientras envía un byte, es decir, si hay pendiente algo por enviar
        UCA1TXBUF = tx_buffer[i+255];                   // Envía un byte a la vez
    }

    while (!(UCA1IFG & UCTXIFG));
    UCA1TXBUF = 0x0A;
}

void Selector_Mux(void)
{
    switch(contador_timer3)
        {
        case 0:
            P4OUT &= ~BIT3;
            P4OUT &= ~BIT0;
            P3OUT &= ~BIT7;
            break;
        case 1:
            P4OUT &= ~BIT3;
            P4OUT &= ~BIT0;
            P3OUT |= BIT7;
            break;

        case 2:
            P4OUT &= ~BIT3;
            P4OUT |= BIT0;
            P3OUT &= ~BIT7;
            break;

        case 3:
            P4OUT &= ~BIT3;
            P4OUT |= BIT0;
            P3OUT |= BIT7;
            break;

        case 4:
            P4OUT |= BIT3;
            P4OUT &= ~BIT0;
            P3OUT &= ~BIT7;
            break;

        case 5:
            P4OUT |= ~BIT3;
            P4OUT &= ~BIT0;
            P3OUT |= BIT7;
            break;

        case 6:
            P4OUT |= BIT3;
            P4OUT |= BIT0;
            P3OUT &= ~BIT7;
            break;

        case 7:
            P4OUT |= BIT3;
            P4OUT |= BIT0;
            P3OUT |= BIT7;
            break;
        }
}

int main(void)
{

    WDTCTL = WDTPW | WDTHOLD;   // stop watchdog timer

    Configurar_GPIO();
    Configurar_TimerA();
    Configurar_ADC();
    Configurar_UART();

    __enable_interrupt();                   // Activa las interrupciones globales

    while(1)
    {
        if(bandera_inicializar==0x01)       //Si se manda la activación desde la computadora, se manda la información
        {
            if(banderaADC_Activar==0x01)
            {
                Adquirir_ADC_Canal0();
                Adquirir_ADC_Canal1();
                Adquirir_ADC_Canal2();
                Adquirir_ADC_Canal3();

                Transformar_Informacion_ADC1();
                Transformar_Informacion_ADC2();
                Transformar_Informacion_ADC3();
                Transformar_Informacion_ADC4();

                banderaADC_Activar=0x00;
                banderaTimer_Activar = 0x01;

                contador_general++;

                if(contador_general==136)
                {
                    bandera_inicializar=0x00;
                    Mandar_Informacion();
                    contador_arreglo1 = 0;
                    contador_arreglo2 = 8;
                    contador_arreglo3 = 16;
                    contador_arreglo4 = 24;

                    contador_arreglo1_2 = 0;
                    contador_arreglo2_2 = 0;
                    contador_arreglo3_2 = 0;
                    contador_arreglo4_2 = 0;
                }
            }
        }
    }

}

// Rutina de interrupción del Timer 0
#pragma vector=TIMER0_A0_VECTOR
__interrupt void TIMER0_A0_ISR(void)
{
    if(bandera_inicializar==0x01)                       //Si se manda la activación desde la computadora, se manda la información del timer
    {
        if(banderaTimer_Activar == 0x01)
        {
            P1OUT ^= 0x01;                                  // XOR al P1.0, este funcionará como un indicador de funcionamiento. Solo bajaremos la velocidad del Timer cuando lo requiramos

            contador_timer++;

            if(contador_timer==1)                           //Pulso principal a 1ms el cual inicia el barrido de Shift Register
            {
                P1OUT |= BIT5;                              //SH_CP del shift register se manda a 1 (ver Proteus)
                if(contador_timer2==0)                      //Si es la primera vez que se acciona el shift register
                {
                    P1OUT |= BIT4;                              //DS del del shift register se manda a 1 (ver proteus)
                }
                else                                        //Se desactiva el DS del shift register para que deje de mandar nuevos pulsos del barrido
                {
                    P1OUT &= ~BIT4;                         //DS del del shift register se manda a 0 (ver proteus)
                }
                P1OUT &= ~BIT3;                             //ST_CP del shift register se manda a 0 (ver proteus)
            }
            else if(contador_timer==2)
            {
                contador_timer=0;               //Se resetea el contador_timer para que se reinicie la maquina de estados
                contador_timer2++;

                P1OUT &= ~BIT5;                 ////SH_CP del shift register se manda a 0 (ver Proteus)
                if(contador_timer2==17)         //Cuando el pulso del shift register llega a la fila 17
                {
                    P1OUT |= BIT4;              //DS del del shift register se manda a 1 (ver proteus)
                    contador_timer2=0;          //Se resetea el contador_timer2 para que vuelva a mandar el pulso de activiación al shift register
                    contador_timer3++;          //Aumena la cuenta para cambiar la selector del MUX (ver proteus)
                    if(contador_timer3==8)      //Cuando sea la última opción del selector: "111"
                    {
                        contador_timer3=0;      //Re resetean los selectores del mux a "000"
                    }
                    Selector_Mux();             //Función para la selección de los multiplexores
                }
                else
                {
                    P1OUT &= ~BIT4;             ////DS del del shift register se manda a 0 (ver proteus)
                }
                P1OUT |= BIT3;                  ////ST_CP del shift register se manda a 0 (ver proteus)

                banderaADC_Activar=0x01;        //Bandera que desactiva al ADC
                banderaTimer_Activar = 0x00;    //Bandera que desactiva al Timer
            }

        }
    }
}

// Rutina de interrupción de UART
#pragma vector=USCI_A1_VECTOR
__interrupt void USCI_A1_ISR(void)
{
  switch(__even_in_range(UCA1IV,4))
  {
  case 0:break;                             // Vector 0 - No hay interrupción
  case 2:                                   // Vector 2 - RXIFG
    while(!(UCA1IFG & UCTXIFG));            // Espera mientras envía un byte, es decir, si hay pendiente algo por enviar
    if(UCA1RXBUF=='I')                      //Si adquiere una A, comenzará a mandar información y el Timer se activará
    {
        bandera_inicializar=0x01;           //Bandera que permite el trabajo del ADC y Timer
        banderaTimer_Activar = 0x01;        //Bandera que activa al Timer
    }
    else if(UCA1RXBUF=='D')
    {
        bandera_inicializar=0x00;           //Bandera que desactiva al ADC y Timer
    }
    break;
  case 4:break;                             // Vector 4 - TXIFG
  default: break;
  }
}

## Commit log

2022-09-26 PCB and Microcontroller data
2024-05-09 Update files
    [4x_Male_Pin_2.54_mm.STEP, 74HC4051-mux.f3d, 74HC4051-mux.step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]
